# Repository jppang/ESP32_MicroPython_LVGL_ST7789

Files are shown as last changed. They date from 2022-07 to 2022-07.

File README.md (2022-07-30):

# ESP32_MicroPython_LVGL_ST7789
Try to build an ESP32 MicroPython firmware with LVGL and ST7789 drivers inside.



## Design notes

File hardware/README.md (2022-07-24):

This development kit for experimenting MicroPython and LVGL on ESP32 platform is designed by KiCad 6.

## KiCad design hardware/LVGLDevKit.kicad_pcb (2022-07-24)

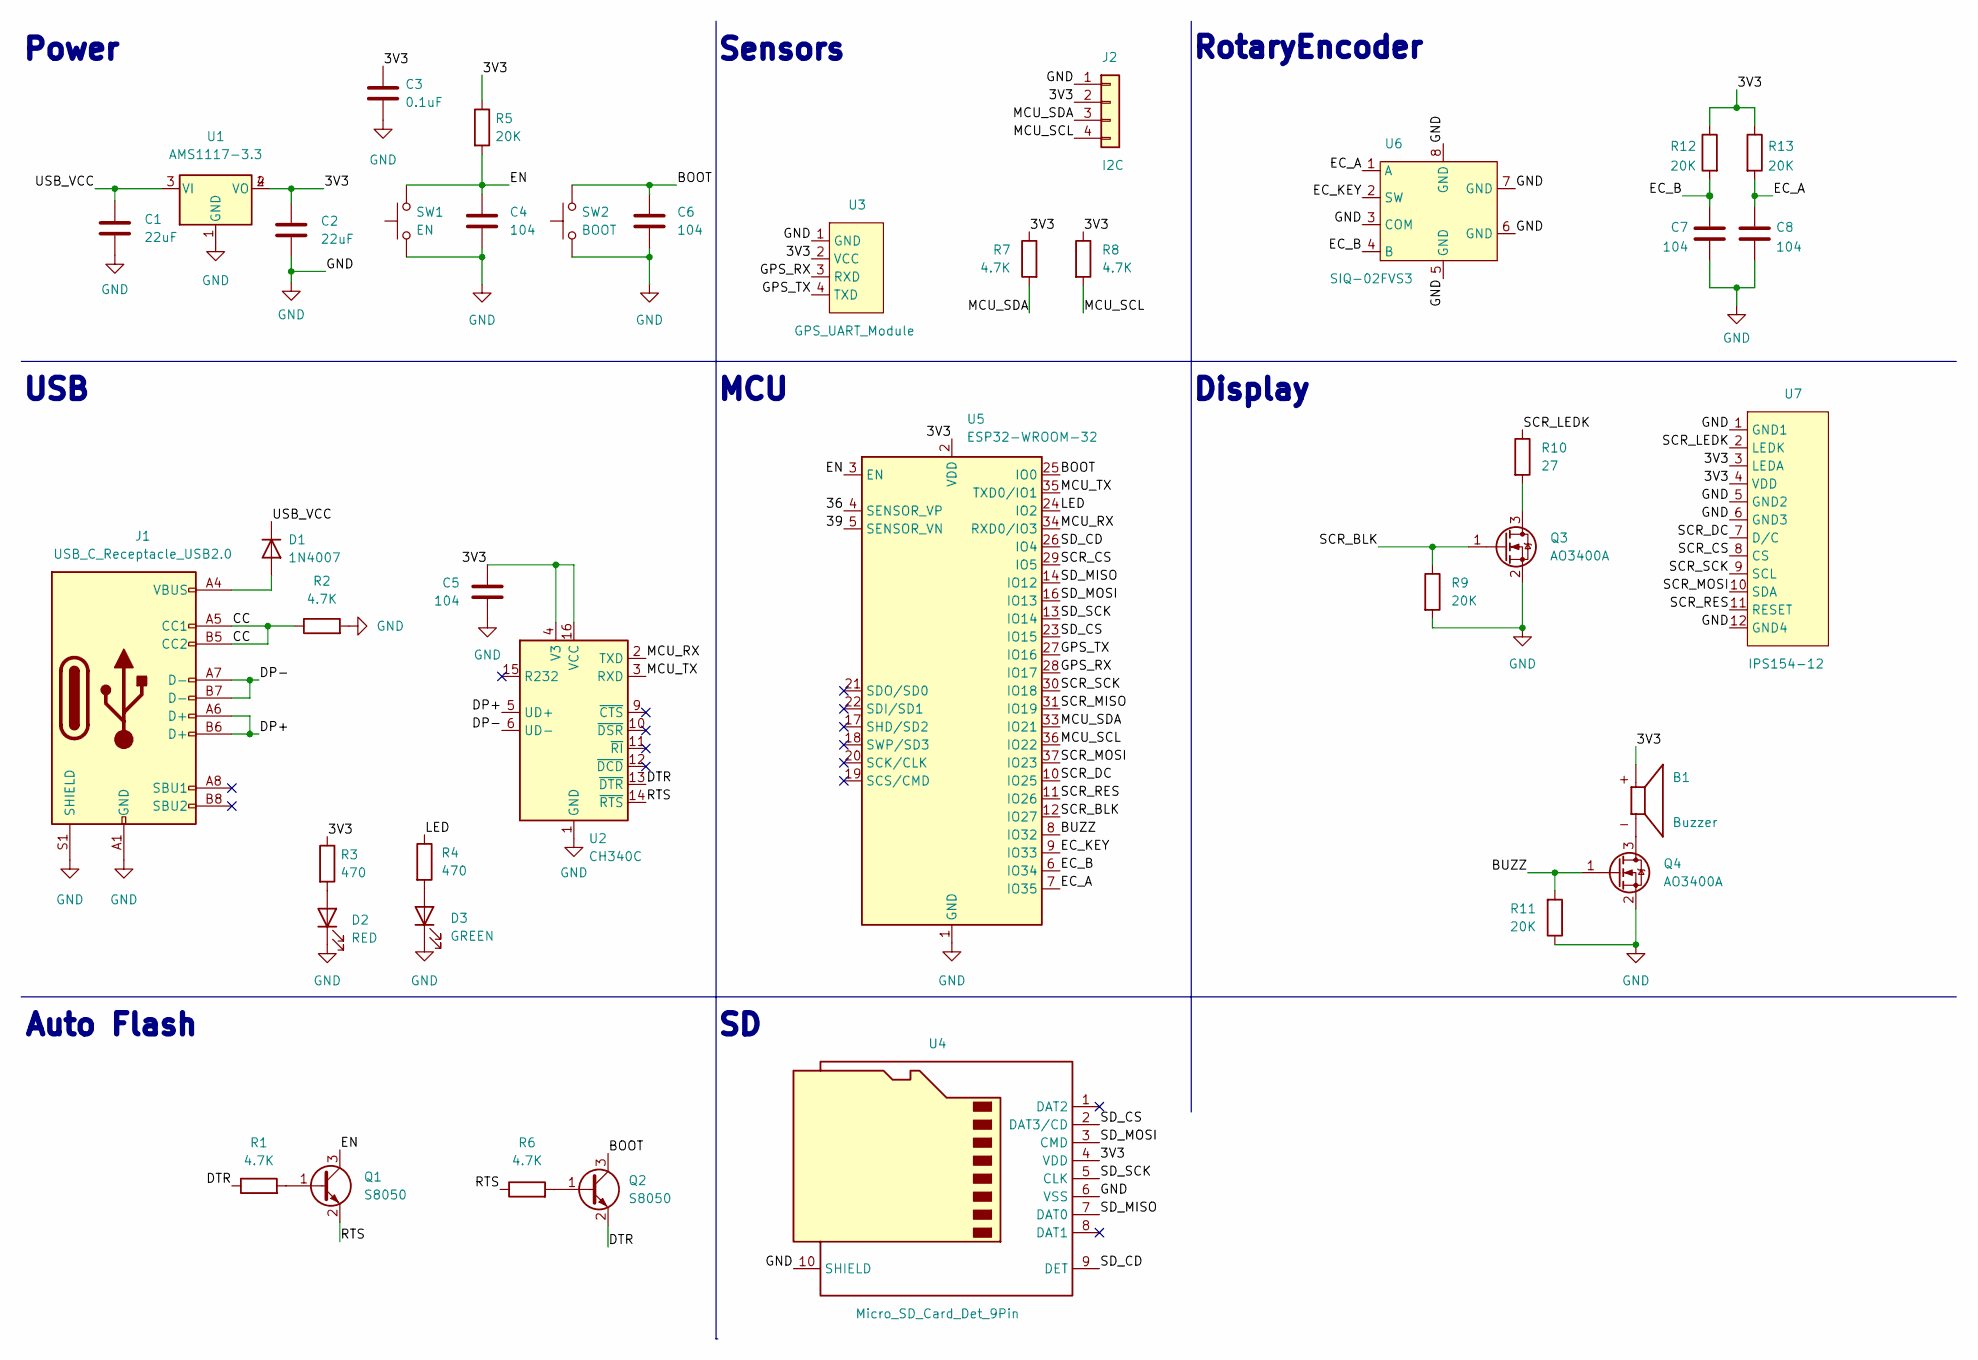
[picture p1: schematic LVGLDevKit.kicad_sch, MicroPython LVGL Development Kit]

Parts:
B1: Buzzer; Buzzer_CMT-0502-75-SMT-TR; PARTREV 1.0
C1, C2: 22uF; C_0805_2012Metric_Pad1.18x1.45mm_HandSolder
C3: 0.1uF; C_0805_2012Metric_Pad1.18x1.45mm_HandSolder
C4, C5, C6, C7, C8: 104; C_0805_2012Metric_Pad1.18x1.45mm_HandSolder
D1: 1N4007; D_SOD-323_HandSoldering
D2: RED; LED_0805_2012Metric_Pad1.15x1.40mm_HandSolder
D3: GREEN; LED_0805_2012Metric_Pad1.15x1.40mm_HandSolder
J1: USB_C_Receptacle_USB2.0; USB_C_Tabobao_16_Pin
J2: I2C; JST_PH_B4B-PH-K_1x04_P2.00mm_Vertical
Q1, Q2: S8050; SOT-23_Handsoldering
Q3: AO3400A; SOT-23_Handsoldering
Q4: AO3400A; SOT-23
R1, R2, R6, R7, R8: 4.7K; R_0805_2012Metric_Pad1.20x1.40mm_HandSolder
R3, R4: 470; R_0805_2012Metric_Pad1.20x1.40mm_HandSolder
R5, R9, R11, R12, R13: 20K; R_0805_2012Metric_Pad1.20x1.40mm_HandSolder
R10: 27; R_0805_2012Metric_Pad1.20x1.40mm_HandSolder
SW1: EN; SW_Push_SPST_NO_Alps_SKRK
SW2: BOOT; SW_Push_SPST_NO_Alps_SKRK
U1: AMS1117-3.3; SOT-223
U2: CH340C; SOP-16_3.9x9.9mm_P1.27mm
U3: GPS_UART_Module; JST_PH_B4B-PH-K_1x04_P2.00mm_Vertical
U4: Micro_SD_Card_Det_9Pin; microSD_Taobao_9_Pin_CD
U5: ESP32-WROOM-32
U6: SIQ-02FVS3; RotaryEncoder_Mitsumi_SIQ02FVS3
U7: IPS154-12; ZJYIPS154_PG04

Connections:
/3V3: B1.P, C2.1, C3.1, C5.1, J2.2, R3.1, R5.1, R7.1, R8.1, R12.1, R13.1, U1.2 (VO), U1.4 (VO), U2.4 (V3), U2.16 (VCC), U3.2 (VCC), U4.4 (VDD), U5.2 (VDD), U7.3 (LEDA), U7.4 (VDD)
/36: U5.4 (SENSOR_VP)
/39: U5.5 (SENSOR_VN)
/BOOT: C6.1, Q2.3 (C), SW2.2, U5.25 (IO0)
/BUZZ: Q4.1 (G), R11.2, U5.8 (IO32)
/CC: J1.A5 (CC1), J1.B5 (CC2), R2.1
/DP+: J1.A6 (D+), J1.B6 (D+), U2.5 (UD+)
/DP-: J1.A7 (D-), J1.B7 (D-), U2.6 (UD-)
/DTR: Q2.2 (E), R1.1, U2.13 (~DTR)
/EC_A: C8.1, R13.2, U5.7 (IO35), U6.1 (A)
/EC_B: C7.1, R12.2, U5.6 (IO34), U6.4 (B)
/EC_KEY: U5.9 (IO33), U6.2 (SW)
/EN: C4.1, Q1.3 (C), R5.2, SW1.2, U5.3 (EN)
/GPS_RX: U3.3 (RXD), U5.28 (IO17)
/GPS_TX: U3.4 (TXD), U5.27 (IO16)
/LED: R4.1, U5.24 (IO2)
/MCU_RX: U2.2 (TXD), U5.34 (RXD0/IO3)
/MCU_SCL: J2.4, R8.2, U5.36 (IO22)
/MCU_SDA: J2.3, R7.2, U5.33 (IO21)
/MCU_TX: U2.3 (RXD), U5.35 (TXD0/IO1)
/RTS: Q1.2 (E), R6.1, U2.14 (~RTS)
/SCR_BLK: Q3.1 (G), R9.1, U5.12 (IO27)
/SCR_CS: U5.29 (IO5), U7.8 (CS)
/SCR_DC: U5.10 (IO25), U7.7 (D/C)
/SCR_LEDK: R10.1, U7.2 (LEDK)
/SCR_MISO: U5.31 (IO19)
/SCR_MOSI: U5.37 (IO23), U7.10 (SDA)
/SCR_RES: U5.11 (IO26), U7.11 (RESET)
/SCR_SCK: U5.30 (IO18), U7.9 (SCL)
/SD_CD: U4.9 (DET), U5.26 (IO4)
/SD_CS: U4.2 (DAT3/CD), U5.23 (IO15)
/SD_MISO: U4.7 (DAT0), U5.14 (IO12)
/SD_MOSI: U4.3 (CMD), U5.16 (IO13)
/SD_SCK: U4.5 (CLK), U5.13 (IO14)
/USB_VCC: C1.1, D1.1 (K), U1.3 (VI)
GND: C1.2, C2.2, C3.2, C4.2, C5.2, C6.2, C7.2, C8.2, D2.1 (K), D3.1 (K), J1.A1 (GND), J1.A12 (GND), J1.B1 (GND), J1.B12 (GND), J1.S1 (SHIELD), J2.1, Q3.2 (S), Q4.2 (S), R2.2, R9.2, R11.1, SW1.1, SW2.1, U1.1 (GND), U2.1 (GND), U3.1 (GND), U4.6 (VSS), U4.10 (SHIELD), U5.1 (GND), U5.15 (GND), U5.38 (GND), U5.39 (GND), U6.3 (COM), U6.5 (GND), U6.6 (GND), U6.7 (GND), U6.8 (GND), U7.1 (GND1), U7.5 (GND2), U7.6 (GND3), U7.12 (GND4)
unnamed: B1.N, Q4.3 (D)
unnamed: D1.2 (A), J1.A4 (VBUS), J1.A9 (VBUS), J1.B4 (VBUS), J1.B9 (VBUS)
unnamed: D2.2 (A), R3.2
unnamed: D3.2 (A), R4.2
unnamed: Q1.1 (B), R1.2
unnamed: Q2.1 (B), R6.2
unnamed: Q3.3 (D), R10.2

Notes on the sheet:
RotaryEncoder
USB
Display
MCU
Power
Auto Flash
Sensors

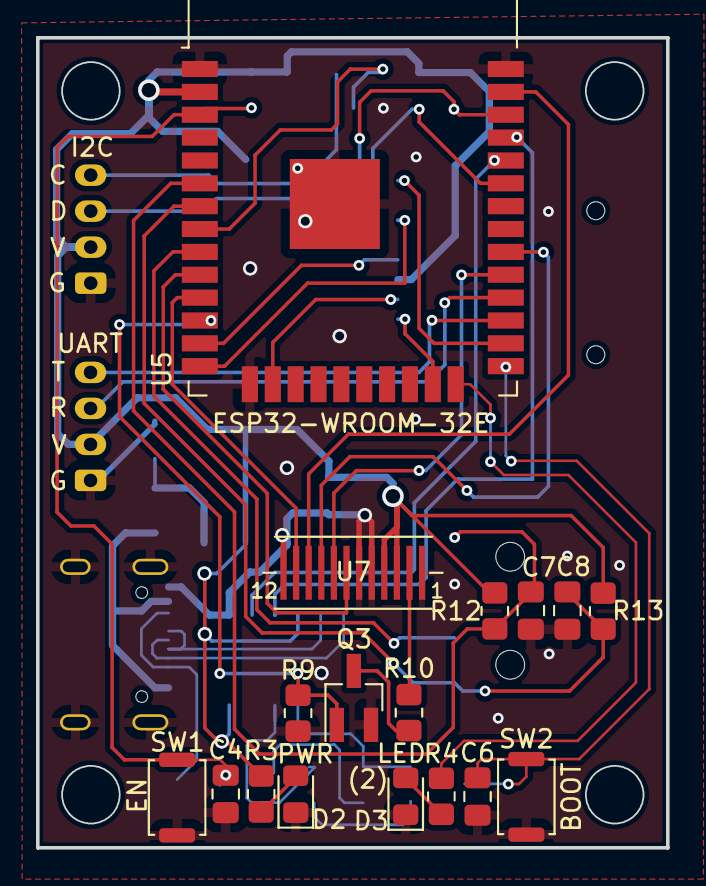
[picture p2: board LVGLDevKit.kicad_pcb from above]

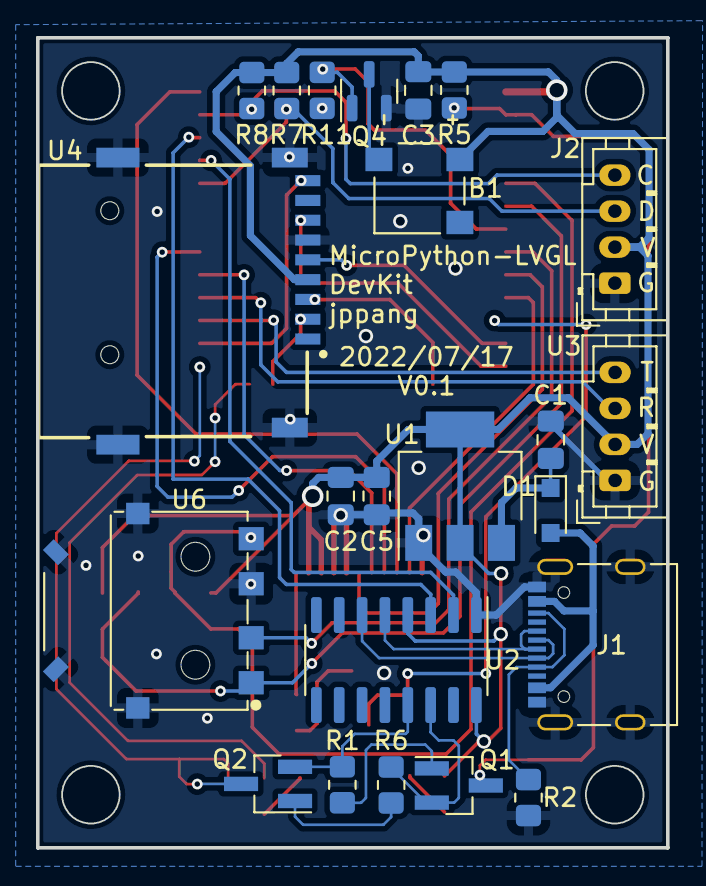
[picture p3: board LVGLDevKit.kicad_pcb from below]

Board: 2 copper layers, 35.0 x 45.0 mm, 40 parts (23 on the bottom side), 40 nets.
